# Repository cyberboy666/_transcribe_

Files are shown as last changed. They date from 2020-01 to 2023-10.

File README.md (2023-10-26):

# \_transcribe\_

### midi to rs232 bridge - for performance control of old video mixers and switchers



- this circuit is distributed by __UNDERSCORES__ - _an open video hardware label_ : it is available to purchase - as a pcb, kit or assembled unit - at [underscores.shop](https://underscores.shop/_transcribe_/)
- the schematic for the circuit can be found [here](/hardware/schematic.pdf)
- the pcb gerber files for the lastest version can be found [here](/hardware/gerber_latest.zip)
- interactive BOM is [here](https://htmlpreview.github.io/?https://github.com/cyberboy666/_transcribe_/blob/main/hardware/bom/ibom.html)
- consider [donating](https://opencollective.com/underscores) to the underscores project to help us continue creating for the commons
## description

people in the video-art community are performing with old hardware video-mixers such as the Pansonic_WJ_AVE55 and Pansonic_WJ_MX30/50. some of these mixers have a RS232 serial port for interfacing with them digitally. this is especially useful for live performance where sequencing can assist physical actions. there are some cool examples of software specifically written to interface with these mixers (such as [Freds excel app](https://a2m2.ch/fred/wj-ave55.htm) and  [Klifs MaxPatch](https://vimeo.com/161662975) ) , but there many more programs and devices that are made to interface digitally using MIDI.

the aim of this project is to create a small utility module that can __\_transcribe\___ _MIDI_, a protocol used commonly in live&performance instruments to the specific _RS-232 video-device specification_ , to better equip these retired workstations for their new life of glamour on stage

- input USB-midi from a USB-HOST such as a computer or rpi
- input serial-midi from older midi devices (din5)
- input USB-midi for a USB-DEVICE such as a korg nanokontroller or otherwise
- output RS232-serial commands over 3.5mm jack or dsub9 socket to control panasonic video-mixers and other devices
- all these interfaces are bi-directional and so can be modified with firmware to do other useful things (eg like a USB-DEVICE -> SERIAL midi converter)

## demo video

(https://videos.scanlines.xyz/w/iJpDAtjqwNczxP9pRJbMGW)

# documentation

this project is fully _open-source hardware_ - all the files required to build it are included in this repo for free. if you have the time and/or skill you can contribute back by collaborating on / testing new designs, improving these docs, making demo videos/other creative content etc. you can also support the project financially by [donating directing](https://opencollective.com/underscores), or purchasing through the [web shop](https://underscores.shop).

depending on whether you are going fully diy or buying an assembled and tested unit, some of the following guides will be relavent to you. the flow would be:

## ordering parts

<details><summary><b>parts sourcing guide (w/ notes on pcb fabracation )</b> - start here if you are building fully from scatch or have purchased a pcb</summary>

i try to source all the parts i can from either:
- [tayda](https://www.taydaelectronics.com/) ; cheaper for common parts like resistors etc, also good for mechanical parts like switches and buttons
- [mouser](https://www.mouser.de/) ; has lots more options, speciality video ic's, can sometimes cost more (free shipping on orders over 50euros)
- other ; ocationally there will be parts which will need to be sourced elsewhere - usaully either aliexpress, ebay or amazon etc...

take a look at the [full_bom](/hardware/bom/full_bom.csv) for this project to see where i am sourcing each part from
  
## omitting parts
  
if you know exactly how you will use your _transcribe_ some parts of this circuit build can be omitted. the pcb is divided into sections that are marked on silk-screen:

- __A - micro-conntroller - centre__ : this is the brain of the circuit and is required to make it do anything. its also where USB_MIDI is received from(/sent to) usb-hosts (eg computer or raspberry pi)
- __B - rs232 serial - output(/input)__ : for sending(/receiving) serial at rs232 levels - only omit if you are not using this board for its default / intended purpose
- __C - serial midi - input(/output)__ : for receiving(/sending) midi messages over serial (usually on older hardware over din5 or 3.5mm jack) - can omit if you are only using (newer) hardware with USB-MIDI
- __D USB-midi HOST__: adds circuitry so that micro-controller can act as USB-HOST. for receiving midi messages from(/sending to) usb-devices (eg korg nanokontrol2) - can omit this if not interested in controlling from usb-devices

## import into tayda

- go to the [tayda quick order](https://www.taydaelectronics.com/quick-order/) and in bottom corner choose _add from file_
- select the file [tayda_bom.csv](./hardware/bom/tayda_bom.csv) in the BOM folder (you will have to download it first or clone this repo)
- after importing select _add to cart_
- __NOTE:__ the minimum value for resistors is 10, so you may need to modify these values to add to cart (or if they are already modified here you will need to see the  full_bom for actual part QTY) 

- OPTIONAL: it is a good idea to add some dip-ic sockets and 2.54pin headers/sockets to your tayda order if you dont have them around already
  
## import into mouser

- go to [mouser bom tool](https://nz.mouser.com/Bom/) and click _upload spreadsheet_
- select the file [mouser_bom.csv](./hardware/bom/mouser_bom.csv) in this folder (you will have to download it first or clone this repo), then _upload my spreadsheet_ and _next_
- ensure that __Mouser Part Number__ is selected in the dropdown above the first row, then _next_, _process_
- if everything looks correct can now put _add to basket_

# ordering pcbs

you can support this project by buying individual pcbs from the [shop](https://underscores.shop). if you would rather have pcbs fabricated from gerbers directly the file you need is [here](/hardware/gerber_latest.zip) 

- i get my pcbs fabricated from [jlcpcb](https://cart.jlcpcb.com/quote) - 5 is the minumum order per design
- upload the zip file with the `add gerber file` button
- the default settings are mostly fine - set the __PCB Qty__ and __PCB Color__ settings (you can check that the file looks correct with pcb veiwer)
- it may be best to combine orders with other pcbs you want to have fab'd since the shipping can cost more than the items - also orginising group buys is a good way to distribute the extra pcbs /costs 
  
i often use jlcpcb because they are reliable, cheap and give you an option of colours. remember though that the cheapest Chinese fab houses are not always the most ethical or environmently friendly - if you can afford it consider supporting local companies. 

</details>

<details><summary>a note on midi over 3.5mm trs jacks</summary>

in general newer devices send midi over usb, and older ones send serial-midi over _din5 jacks_. however some newer devices opt to send serial-midi over __3.5mm trs jacks__ (to save space on more compact designs)

_transcribe_ has (overlapping) footprints for either serial-midi over _din5_ or over __3.5mm trs__

unfortunately at the time that designers started using __3.5mm trs jacks__ for midi there was no offical standard for which pins map to midis _source_ (`midi_plus`) and _sink_ (`midi_data`) pins and different designers have mapped this differently on their instruments.

now there is an offical standard - TYPE A - which is what _transcribe_ uses: 

- t -> _sink_ (data)
- r -> _source_ (plus)
- s -> x

[minimidi.world](https://minimidi.world/) is a great resource that explains the different standards and allows you to look up the type of _serial midi over 3.5mm trs_ that your devices have - i recommend taking a look at this if you are planning on using 3.5mm trs with your _transcribe_

</details>

## assembly guide

<details><summary><b>assembly guide</b> - start here if you have purchased a diy kit</summary>

## interactive BOM for build guiding

follow this link to view the [interactive BOM](https://htmlpreview.github.io/?https://github.com/cyberboy666/_transcribe_/blob/main/hardware/bom/ibom.html)

## general solder advices

- remember to heat pad first (2-3seconds), then add solder, then continue to heat (1-2seconds)

- Checkout the web-comic [soldering is easy](https://mightyohm.com/files/soldercomic/FullSolderComic_EN.pdf) for more soldering advice

## general order of assembly

- in general while assembling i start placing resistors and capacitors first. placing 5 - 10 components at a time and then flipping the board to solder them and trim the legs etc.
- next i would do diodes, transistors and ic's - taking care that these are placed in the right direction (using a ic socket can be useful)
- finally i place the interface parts - rca jacks, power jack, pots and switches - make sure these have lots of solder on for structural stablity

## interface choice / double footprint
  
_serial-midi_ is most commonly sent over __din5__ (older hardware) J5 & J7 or __trs 3.5mm jack__ (newer hardware) J4 & J6 - footprints for both are overlayed on the pcb so you can choose which one you would like to have
  
## Usb-host shield

__IMPORTANT: A trace needs to be cut on the usb-host-shield to allow it to be powered by 5v__ – _see the diagram below_ – this is best done with a craft knife – take care not to cut any other traces accidentally.
  


  
all pins on the outer vertical lines need to be soldered to the board. In addition to this the single topmost inner pin (labeled 5v in diagram) needs to be soldered to pcb also
  
## specific assembly advice

Start by soldering the smallest parts first: resistors, diodes, capacitors and regulators - take note of the direction on the diodes - black bar on component matching black bar on footprint

Next lets do the ic’s/sockets - make sure the direction is correct! place in and fold two corner pins to hold in place, then solder all pins. you can place the ic in now too

Now lets do the micro-controller and usb-host-shield - if you want to be able to remove them from the board you will need to solder header sockets to the board first – otherwise can directly solder the header pins

for the usb-host-shield right_row I would do a 1x2 header horizontally at the top to catch that 5v pin and then 1x11 row vertically for the rest – the left_row can just be a single 1x12 vertical header

Finally place the interface parts (eg jacks and sockets) be generous with the solder here -> this is to strengthen the mechanical connections as well as making electrical ones

Leave j8 header unpopulated – this just exposes the bootloader pins so firmware can be reset in the rare case that the pro-micro gets bricked – also leave j1 header unpopulated unless you want to power from a euro-power-header
  
</details>

## firmware guide

<details><summary><b>firmware guide</b> - for editing the code & flashing it to your micro-controller</summary>
  
## flashing firmware onto the micro-controller
  
if you have got a kit from the shop the default firmware will be pre-configured - still you probably will want to follow this so you can edit the code and update the mappings.
  
### install guide
  
all _underscores_ projects with micro-controllers use [platformio](https://platformio.org/) with [visual studio code](https://code.visualstudio.com/) to edit, flash and monitor the code.
  
- first download (and unzip) the code in this repo - easiest is [as a zip](https://github.com/cyberboy666/_transcribe_/archive/refs/heads/main.zip) or you can clone using git if you are comfortable with this
- next download, install and open [visual studio code](https://code.visualstudio.com/#alt-downloads)
- now open the extension tab within vscode on left vertical menu (or press ctrl-shift-x) and search for `platformio` to install this extension
  


- connect the micro-controller to computer via usb, open the _transcribe_ software folder (ctrl-k ctrl-o) in vscode and find the _platformio_ commands (either in left vertical menu under _platformio_ or little tick/arrow symbols along bottom blue bar) - `PlatformIO: Upload` should flash the default code to your micro-controller
  


### mapping edit guide
  
this guide is just an overview to get you started. the two files that you might want to look at are: 
- [software/src/commands.h](software/src/commands.h) - where the specific serial protocol commands are defined
- [software/src/main.cpp](software/src/main.cpp) - all the code that handles receiving midi and writing serial is - including the _mapping function_
  
open the `src/main.cpp` file in vscode and fold all functions by pressing `ctrl-k, ctrl-0` - this makes reading it a bit easier:



open and take a look at the `setAVE55nanokontrolMap` method - we will first look at these lines:
  
```cpp
    else if(midiParam1 == 64){setCmd(A55_A_BUS_SOURCE_1);}
    else if(midiParam1 == 65){setCmd(A55_A_BUS_SOURCE_2);}
```
  
the first line is saying: __if the incoming midi message has `midiParam1` set to 64, then send the `A55_A_BUS_SOURCE_1` command over rs232 serial__ - since we can see from above that this line is within the conditional: `if(midiCommand == MIDICOMMAND::CC)` , then we know that `midiParam1` is refering to the cc channel. we can also see in the __commands.h__ file  that `A55_A_BUS_SOURCE_1` is set to the command from that panasonic ave55 specification that switches the a-bus source to input 1:
```cpp
  #define A55_A_BUS_SOURCE_1 "VCP:200"
```

this line is mapping a midi message on cc channel 64 to the rs232 message for ave55 that switches the input source. this is the simplest kind of mapping - a discrete BUTTON press. however there are also mappings to functions that take parameter values also. for example the `A55_A_B_MIX_LEVEL` command that wipes between the a-bus to b-bus on the mixer:
  
 ```cpp
 if(midiParam1 == 0){setCmd(A55_A_B_MIX_LEVEL, midiParam2);}
 else if(midiParam1 == 1){setCmd(A55_THRESHOLD_LUM_KEY, midiParam2);}
 else if(midiParam1 == 2){setCmd(A55_CENTER_WIPE_X, midiParam2);}
 else if(midiParam1 == 3){setCmd(A55_CENTER_WIPE_Y, midiParam2);}
```

we can see that on these mappings also the __midiParam2__ value is passed into the _setCmd_ function - this is the _cc value_ of the channel - on my controller - the position of the slider that is sending on cc channel 0. the rs232 command for this function also takes a varible input to set position of the mix:
```cpp
#define A55_A_B_MIX_LEVEL "VMM:179~0"
```
where the `~0` is a placeholder that is replaced with the hex-converted value of `midiParam2`. there are other ways to map midi notes to rs232 commands. there are more 'advanced' mapping functions in the code for this - for example:
```cpp
else if(midiParam1 == 35){setCmdParamRandom(A55_A_B_MIX_LEVEL);}
```
takes a button press and converts it to a random mix level. another useful mapping is taking continuous inputn (eg slider on midi controller)  and convert this to a STEP of different discrete commands - for example:
```cpp
else if(midiParam1 == 17){setCmdStepAVE55(A55_A_BUS_MOSAIC_OFF, midiParam2, 76, 6);}
else if(midiParam1 == 18){setCmdStepAVE55(A55_A_BUS_PAINT_OFF, midiParam2, 82, 6);}
```
these mappings STEP between sending 6 different rs232 commands on a single slider - so you can set all the mosaic/paint effect levels in one turn. another useful 'advanced' mapping function is the SWITCH:
  
```cpp
else if(midiParam1 == 50){setCmdSwitch(MX50_A_BUS_EFFECT_ON, MX50_A_BUS_EFFECT_OFF, 3);}
```

this will SWITCH between sending the _on_ and _off_ commands when the same midi command is send (the third parameter input `3` is a unique index reference to store the on/off state in memory between messages)
  
these are just some examples of the ways that code can be used to perform these mappings. if you are interested can see more in the code directly or write your own mapping functions!

</details>
  
## operating guide
  
<details><summary><b>operating guide</b> - start here if you have purchased an assembled unit</summary>



</details>

### more info

<details><summary><b>how the circuit works</b></summary>
  
[coming soon]
                                                                                                                             
</details>

<details><summary><b>contributing guide</b></summary>
  
if you would like to contribute back to these projects in some way but dont know how the best thing (for now) would be to reach out to me directly ( tim@cyberboy666.com or @cyberboy666 on scanlines forum) - i will be happy to help
  
</details>

## credits & more info

This circuit is distributed through UNDERSCORES – open video hardware label – visit [underscores.shop](https://underscores.shop) for more info

The pcb was designed using KICAD

Everything from gerbers, cad files, panels and documentation is freely available online and distributed under CC-BY-SA / open-source licenses – help us contribute to the commons !

Ask any questions or start discussions related to this project on the [scanlines.xyz](https://scanlines.xyz) forum – an online community space dedicated to diy av / electronic media art

You can contact me directly at tim (at) cyberboy666 (dot) com 
Please get in touch if you are interested in hosting a workshop !



Thanks to Gilbert Sinnott for helping with initial experiments. to Bastien Lavaud for circuit advice, always. To Ben Caldwell for project advice. To everyone who has or will contribute ♥♥♥

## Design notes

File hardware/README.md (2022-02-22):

# _transcribe_ hardware

this is the hardware section of _transcribe_ - a project created to control panasonic video_mixers with midi.

# BOM

Reference | Qty | Value | source | source-id | section
--- | --- | --- | --- | --- | ---
? | 1|  _transcribe_ pcb | me? or a fab-house | ...  | all
C1 | 1 | 100uf | tayda | [A-1063](https://www.taydaelectronics.com/catalogsearch/result/?q=A-1063) | A 
C2, C3, C4, C5 | 4 | 0.1uf | tayda | [A-4008](https://www.taydaelectronics.com/catalogsearch/result/?q=A-4008) | B
D1, D2 | 2 | 1N4148 | tayda | [A-157](https://www.taydaelectronics.com/catalogsearch/result/?q=A-157) | C
J1 | 1 | europower header (optional) | tayda | [A-2956](https://www.taydaelectronics.com/catalogsearch/result/?q=A-2956) | -
J2, J4, J6 | 3 | AudioJackTSR | tayda | [A-853](https://www.taydaelectronics.com/catalogsearch/result/?q=A-853) | B , C
J3 | 1 | DSUB9 | tayda | [A-300](https://www.taydaelectronics.com/catalogsearch/result/?q=A-300) or [A-301](https://www.taydaelectronics.com/catalogsearch/result/?q=A-301) | B , C
J5, J7 | 2 | DIN-5 | tayda | [A-1010](https://www.taydaelectronics.com/catalogsearch/result/?q=A-1010) | B , C
R1, R2, R3 | 3 |  220 | tayda | [A-3755](https://www.taydaelectronics.com/catalogsearch/result/?q=A-3755)  | C
R4 | 1 | 10k | tayda | [A-2275](https://www.taydaelectronics.com/catalogsearch/result/?q=A-2275)  | C
U1 | 1 | ProMicro5v | [ali](https://www.aliexpress.com/item/1348800135.html) [amazon](https://www.amazon.com/OSOYOO-ATmega32U4-arduino-Leonardo-ATmega328/dp/B012FOV17O/), [sparkfun](https://www.sparkfun.com/products/12640) | - | A
U2 | 1 | MAX232n | tayda | [A-034](https://www.taydaelectronics.com/catalogsearch/result/?q=A-034) | B
U3 | 1 | 6N137 | tayda | [A-871](https://www.taydaelectronics.com/catalogsearch/result/?q=A-871) | C
U4 | 1 | 4069 |  tayda | [A-882](https://www.taydaelectronics.com/catalogsearch/result/?q=A-882) | C
U5 | 1 | usbHostMini | [ali](https://www.aliexpress.com/item/32842815739.html) [amazon](https://www.amazon.com/HiLetgo-Development-Compatible-Interface-Arduino/dp/B01EWW9R1E/) | - | D
U6 | 1 | 78L33 | tayda | [A-492](https://www.taydaelectronics.com/catalogsearch/result/?q=A-492) | D

<details><summary>CORRECTION FOR CIRCUIT V0.2 AND LOWER</summary>

if you have circuit revision 0.2 or lower then there is a mistake on the footprint of the dsub9 connector sorry (serial from the 3.5mm jack to ave55 works fine) follow the following steps to get serial from the dsub9 header on these boards:

- solder the DSUB9_HEADER onto the bottom of the board
- from here pins 2 and 3 need to be swapped
- cut both traces going to dsub (the traces going between and around c2)
- wire the other ends pin13 and pin14 of u2 to the pins on dsub. u2_pin13 to dusb_pion3 and u2_pin14 to dsub_pin2 
- finally due to another error on the board IF you have placed the 3.5mm jack at J2 THEN you must have a stereo cable plugged into this to use the DSUB9 output (otherwise signal is grounded)




</details>

## potential additional parts to add : 

## assemble guide :

- i soldered the resistors, capicitors, diodes and regulator first, then the ics(/sockets) and pin headers, then the jacks
- i used pin sockets to attach the pro-micro and usb host to board in detatchable way (helpful for debugging) but this is up to you

blah blah blah

IF USING USB_HOST_MIDI YOU __MUST CUT A TRACE__ ON THE BOARD ! heres how - ...

the trace you need to cut is going into the resistor labelled 2.2k in the top corner near the usb socket




# explaining the sections of _transcribe_

 _transcribe_ is based around an arduino micro controller. included in this circuit are a number of different ways to input midi and output serial. you can choose which sections to populate based on your personal requirements.

## A - micro-conntroller - centre

this is the brain of the circuit and is __required__ to make it do anything. i am using a sparkfun pro-micro 5v, which uses micro-usb as power. (it is likely this circuit will also work with an arduino nano - which will require a seperate version of the pcb - but watch this space)

## B - rs232 serial - output(/input)

panasonic video mixers (and other older devices) use a different serial standard (RS232) to micro-controllers (ttl). in this section serial commands from the uC are level-shifted to be recongised by these devices. _only obmit this section if you are not interested in controlling old (rs232) gear_. the data is exposed on a 3.5mm TRS (stereo) jack; tip - input, ring - output, sleave - ground.

NOTE - although not used by the default firmware, the hardware also allows rs232 serial input, so this porject could be modified to also control something _from_ old gear

## C - serial midi - input(/output)

the uC (in A) can act as a USB midi _device_. this means it can be controlled by a USB midi _host_ (such as a computer running abeton, or a raspberry pi). this section includes the additional circuity to also control it with serial-midi (often seen on older instruments with din5 type plugs)

NOTE - although din5 plugs are often used for connecting old gear with serial midi, these sockets can be bulky and sometimes difficult to find. for this reason newer gear supporting serial-midi often use TRS jacks - leaving the standard-conversion to cables. i would use 3.5mm TRS (stereo) also for midi in and out, with tip - midi data (din-pin4), ring - midi plus (din-pin5), sleave - unconnected (or include a switch to swap tip/ring...)

NOTE - although not used by the default firmware, the hardware also allows serial-midi output, so this project could be modified to also output serial midi

_obmit this section if you are not interested in interfacing with 'old style' serial midi_

## D USB-midi HOST

the uC (in A) can act as a USB midi _device_. this means it can be controlled by a USB midi _host_ (such as a computer running abeton, or a raspberry pi). this section includes additional circuitry to allow the uC to also act as a USB midi __HOST__. this means it can be controlled by a USB midi _device_ such as a korg nanokontroller (or many other external usb-midi controllers/ gear). _obmit this section if you are not interested in controlling from a usb-midi device_

# section summary

## video-mixer controlling options:

- control rs232-mixer with usb-midi from host : A + B
- control rs232-mixer with serial-midi : A + B + C
- control rs232-mixer with usb-midi from device : A + B + D

## some bonus converting options:

- convert usb-midi controller to serial midi : A + C + D
- convert rs232 commands to serial-midi : A + B + C
- use a ps3 controller to send serial-midi : A + C + D

## build notes for v0_5

- decide on what sections you want to build (ie need to have A, probably you want to send out serial so also add B. do you want usb-midi ? then add D, do you want serial midi in/out ? then add C etc)
- also decide what kind of serial midi ins/out jack you want - old style din5 or new 3.5mm jack ?
- i started by placing and soldering the caps and resistors, then diodes and regulator (check orientation!)
- i like to solder in pin sockets for the pro-micro and usb-header part so they can be removed if i upgrage the circuit design - this is up to you -> will need to solder in the pins onto the pro-micro and usb-host shield if not already done. note the extra pin needed on host and the trace that needs to be cut!
- if using pin sockets do this next - when cutting the sockets to fit aim your wire cutters exactly on the adjacent socket (one more) than you need - this is to ensure the pin part doesnt fall out of the socket you need when cutting. you may need to bend u6 down abit to fit socket in
- now place the j9 pins (and two jumpers setting the serial pins on din9) and the ic/ic_sockets
- finally can solder on the interface parts - midi ins and outs, din9 and 3.5mm jacks
- note dont need to solder anything on for u5 pins - this is just exposing pins on the pro-micro so it can be reflashed incase of critical error flashing - dont need to place the euroheader either - this is just incase you want to give 5v from an existing europower rail (take care of orientation of the header if doing this)

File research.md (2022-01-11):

whenever i start a project i like to keep a list of ideas, thoughts, srceen-caps and todo lists in one place

# _transcribe_
for midi control of panasonic video mixers

## idea / overview

promicro setup : https://learn.sparkfun.com/tutorials/pro-micro--fio-v3-hookup-guide/all

.... some links here, explaining ...

- take midi in (see different ways below)
- send serial out (for ave55)
- convert to r232 with max232 chip
- connect to 3.5 trs jack

https://arduinodiy.wordpress.com/2012/03/19/serial-connection-for-your-arduino-atmega

wiring max232n : 







## want to support for : 

### usb midi device

usb midi from a host ie computer, pi etc, this should be the easiest to implement

### serial midi

from din midi devices - for this would have to have 2 serial ports, one listening to midi in, and one writing to ave55 out, i thin k the best thing to try is midi on the hardware serial and ave55 on [AltSoftSerial](https://www.pjrc.com/teensy/td_libs_AltSoftSerial.html) , altSoftSerial on pro micro is missing the input pin , but it seems this can be modded in without too much trouble : https://forum.arduino.cc/index.php?topic=339587.0

### usb midi host

from things like nano control - needs a host shield - maybe like [this](https://www.aliexpress.com/item/32942427334.html) one : 

reading midi from host and outputting as serial : https://github.com/felis/USB_Host_Shield_2.0/blob/master/examples/USBH_MIDI/USB_MIDI_converter/USB_MIDI_converter.ino
question about mini-host and pro-micro : https://github.com/felis/USB_Host_Shield_2.0/issues/392
an old thread talking about hooking these up together : https://forum.sparkfun.com/viewtopic.php?t=34873
another thread about hooking these up: https://forum.pjrc.com/threads/43357-Teensy-with-mini-USB-host-shield-(chineese)

### further research into using the usb-host:

- it seems that the vbus (5v) needs to be cut from the vcc (3.3v) , here is best example : https://www.arduino.cn/thread-81435-1-1.html
- i need a 3.3v power source for the usb-host , prob best bet is a L78L33 (18c, up to 100ma) or LM1117T (99c up to 800ma)
- for the wiring , in theroy a level-shifter should be used between 5v arduino and 3.3v ic (74HC125) , but people have reported success with a arduio nano , which is also 5v so im thinking maybe this will also just work ?? but other places suggest it wont ,, im not sure - should try this circuit with a 3.3board too ?
- also a 100uF cap in line with the power is reccomended here : https://www.pjrc.com/teensy/td_libs_USBHostShield.html

- for the wiring , it should look something like this :

host | pro-micro | name
--- | --- | ---
5 | ? | ss
6 | 16 | mosi
7 | 14 | miso
8 | 15 | sck
2 | ? | int
1 | vcc | 5v
9 | regulator | 3.3v
3 | gnd | gnd
4 | rst | rst

- also suggested to wire rst to power ... 

HOST


some more useful info about the host :
- https://www.hackster.io/139994/plug-any-usb-device-on-an-esp8266-e0ca8a
- https://web.archive.org/web/20190120133645/https://www.circuitsathome.com/usb-host-shield-hardware-manual/

## other panansonic (or other) mixers

- panasonic ave55 is rs232 on a stereo 3.5mm jack

- mx50 has a rs232 / rs422 switch , the interface is a 9pin dsub (with a bunch of confusing swtiches / settings)
- mx30 has 9pin dbus with rs232
- mx20 has serial on a mini-din , it says rs422 - hard to tell if it will work or how to make it ...
mx70 has 9pin dsub with rs232 also
- others ??

## some ideas of ideal structure

- ~~a list of mappings between serial commands and midi notes/ccs~~
- ~~continuous controls -> cc values (ie mix position...)~~
- ~~buttons -> notes or cc (sources, )~~
- ~~switches (toggles) -> single note/cc (ie pressing once for on, again for off ?)~~
- ~~range of values (steps) -> cc values (ie paint0, paint1, paint2, paint3)~~

## some things to check / try / do

- try with the level-shifter circuit - i tried but it didnt work - maybe my circuit was wrong tho
- ~~try with smaller caps~~ this works horray
- ~~try with altSoftSerial~~ - seems to work
- ~~try with serial midi input (how?) maybe i will need to work with 2 arduinos , one for sending midi another for receiving~~
- ~~try with usb midi host sheild~~ 
- implement other types of commands (random / osolatoer etc .. )
- create a pcb design

## looking at other  mixers

the other panasonic mixers i know about have a different way of inputing serial... dont even know if this is compatable or works in the same way..

### mx 50 wiring



### mx 30 wiring



crazy that even these two arnt wired the same way ! but maybe only the (tx/rx/gnd matter anyway...)

### mx 20 wiring



dif plug, (mini din) and i think dif wiring too - looks like , oof it makes no sense ! (no mention of buad rate or stop byte or anything really on this one) , maybe not possible to support this one ...

### kramer vs-402 serial spec



## from wikipedia :



# burning the bootloader

it is known that the sparkfun promicro can from time to time get into a state where the port is not recognised, or difficult to upload new code to it - there is a complicated method of grounding the reset pin some times and then quickly uploading new code - i have tried this and though it works sometimes , it also is very frustrating and can just become a problem again the next time you try to upload some code. 

instead i am going to explore the method of reburning the bootloader on the pro-micro, hopefully this will fix the problem more permanently. and after the intial time taken to learn how to do this, it will also save time working on this project, and any others with pro-micros. as a side note - this could also be useful for burning/uploading code to the dip-atmega ics you can get for $2 from tayda...

this [sparkfun article](https://learn.sparkfun.com/tutorials/installing-an-arduino-bootloader) is a good introduction to the idea.

i dont have an uno, but do have an arduino nano here - so will try using this as the ISP. sounds like even another pro-micro will work as ISP according to [this forum](https://forum.arduino.cc/index.php?topic=199524.0) post, but they have caused enough trouble for now !

first i uploaded the ArduinoISP sketch to the nano (using the old bootloader version) , 
then hooked them together with some wires:

the connections were: with spi->spi (miso, mosi, clk), and ss -> rst, plus power/gnd ; exactly the same as in this guide https://www.instructables.com/id/Burn-Bootloader-Arduino-Nano-As-ISP-to-Pro-Micro/ ; also i put a 10uf cap reset -> +| |- ->gnd on the nano

then in the arduino ide i chose the pro-micro board, changed the programmer to `arduino as ISP` then pressed `BurnBootloader`. this worked no problem ! very painless. at first i followed the intructable above and loaded with the  `arduino Micro` board selected, but this did weird things with the leds , and although it still worked, after trying with my other 'not working' pro-micro , this newly updated one also started having problems.. i then went back and reburnt the bootloader , now with `sparkfun pro-micro` board selected - this fixed the weird led thing.

even with the pro-micro burnt, if i try upload code with the problem board, then swich the cables to a fresh and working one (even with a reset of vscode between) it will pass on the problem to this fresh board. luckly reburning the bootloader is very quick if you have the nano set up and ready to go. i will keep this ISP nano handy on the breadboard while developing on the pro-micro in case this problem starts again.

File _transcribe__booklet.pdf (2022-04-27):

# _transcribe_

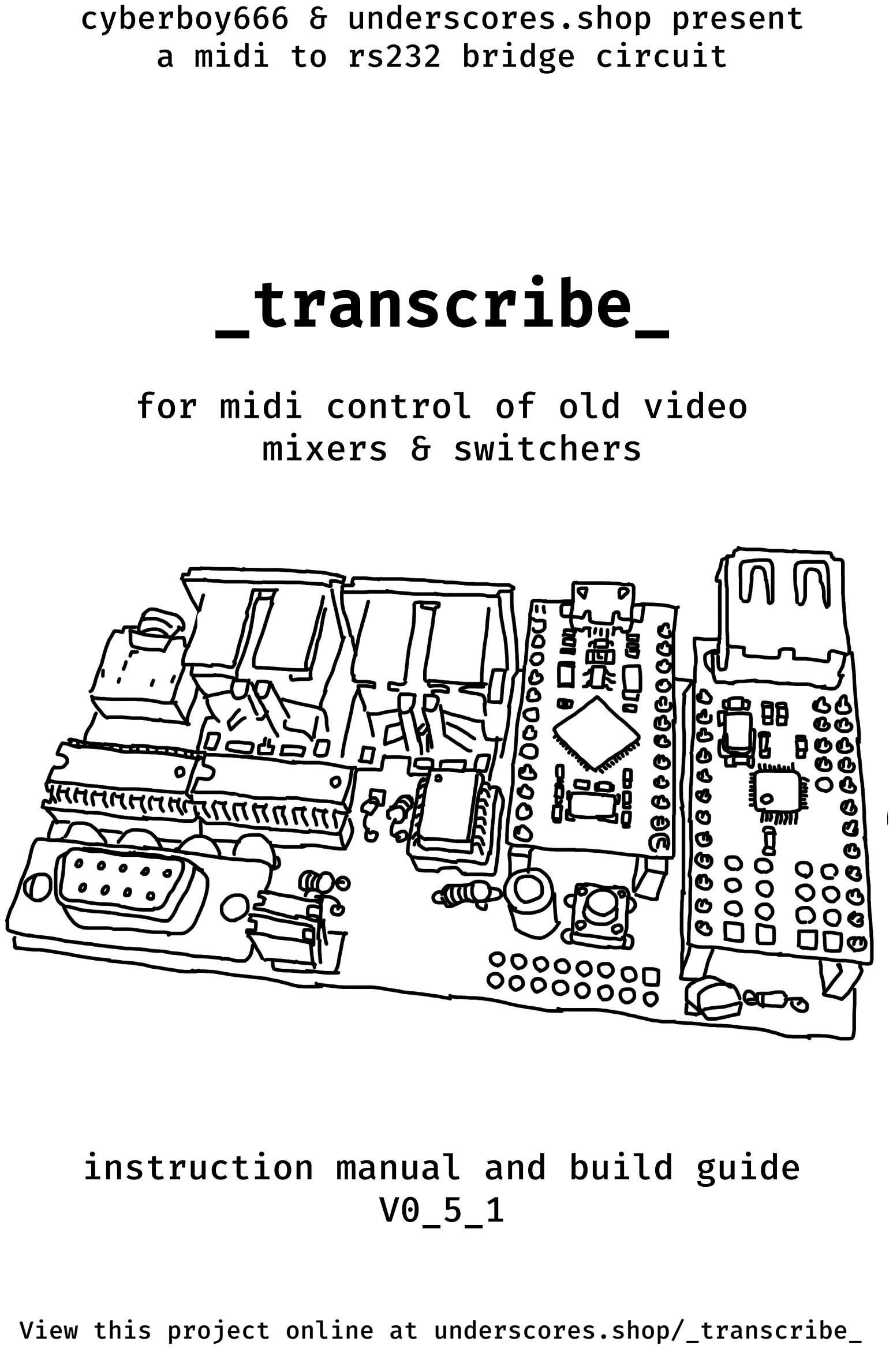
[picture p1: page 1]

cyberboy666 & underscores.shop present a midi to rs232 bridge circuit

### for midi control of old video mixers & switchers

### instruction manual and build guide

## V0_5_1

View this project online at underscores.shop/_transcribe_

\

# INTRODUCTION

the _transcribe_ circuit is a midi to rs232 serial utility module aiming to give better integrated performance capability to older/obsolete video gear.

some old video mixers and switchers have their own serial command specifications for externally controlling them. the arduino micro-controller in _transcribe_ runs open source firmware that maps incoming generic midi messages to these specific serial commands.

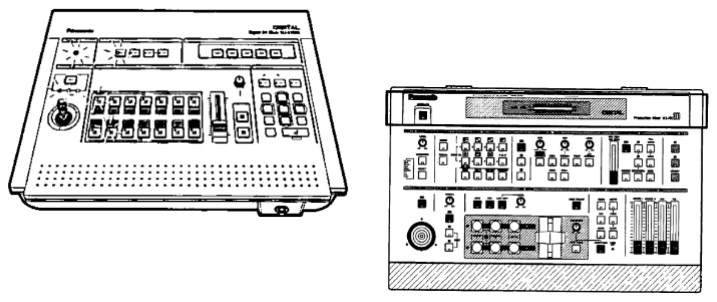
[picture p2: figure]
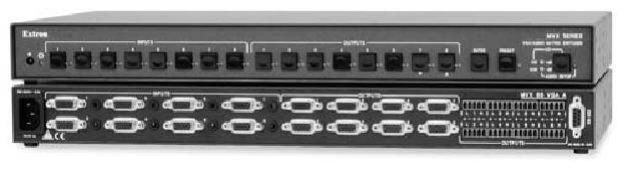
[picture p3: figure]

- So far _transcribe_ is tested and supported with:
- Panasonic ave55
- Panasonic mx30/50 (partial)
- Extron video switchers
- Kramer video switchers

More devices will be added as people start experimenting with the gear they have around – let me know if you are interested in helping add support for something!

# FIRMWARE MAPPING

although no coding background is required for this project, you will need to be comfortable following install instructions and hacking at a few lines of arduino code to customize and set up your own midi to rs232 mapping

There are guides to both installing the required software and in-depth explanations to how the code that does the mapping works on the projects github page: github.com/cyberboy666/_transcribe_

An example of a default mapping for the panasonic ave55 can be seen below

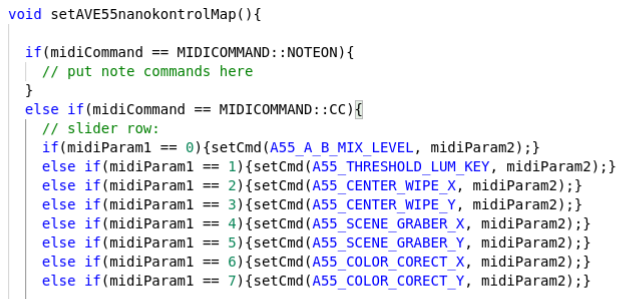
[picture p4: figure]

Don’t worry if all this doesn’t make sense initially – most of the heavy lifting being done under the hood, you just need to say on which midi messages should trigger which serial commands.

However if you do know some c++ theres room in the code to add some esoteric and fun mapping functions such as setting random wipe positions and types on every note etc..

# OPERATING INSTRUCTIONS

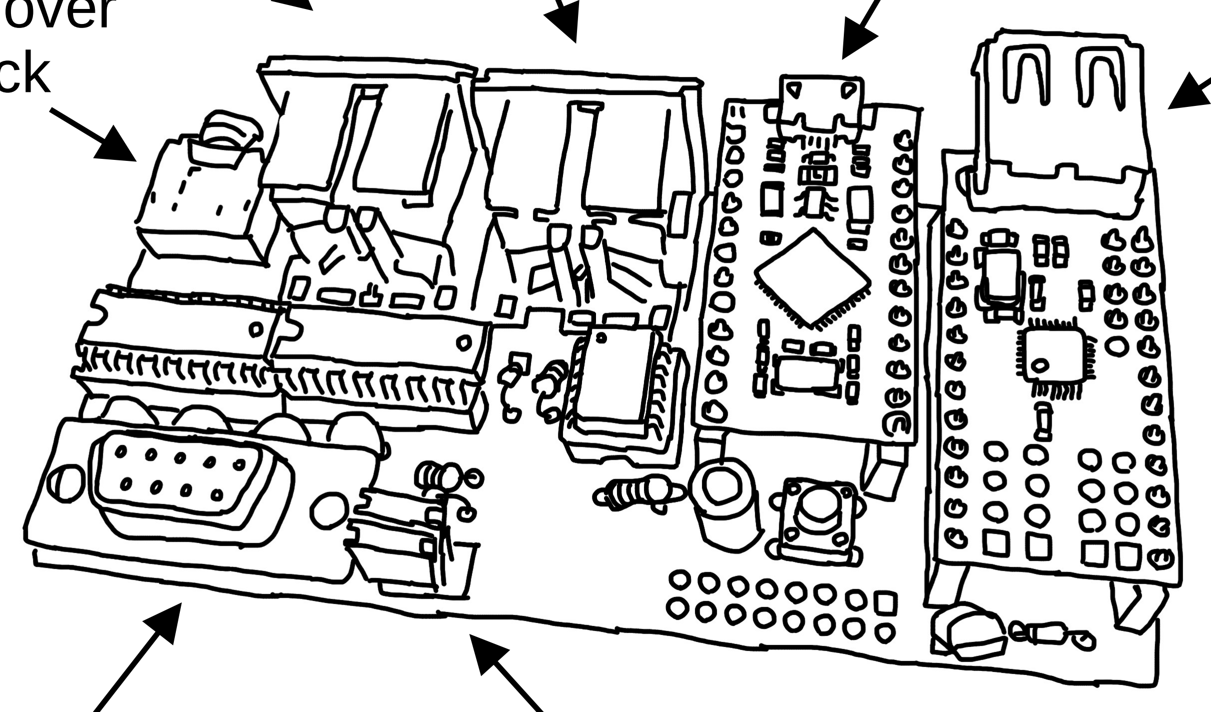
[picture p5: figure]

There are a few different options for inputting midi into _transcribe_ and outputting serial, depending what you are connecting to it:

- input USB-midi from a USB-HOST such as a computer or rpi
- input serial-midi from older midi devices (din5)
- input USB-midi from a USB-DEVICE such as a korg nanokontroller2 or otherwise
- output RS232-serial commands over 3.5mm jack or dsub9 socket to control panasonic video-mixers and other devices
- all these interfaces are bi-directional and so can be modified with firmware to do other useful things (eg like a USB-DEVICE midi -> SERIAL midi converter)

rs232 serial over
3.5mm jack

midi from USB-DEVICES

serial midi in

rs232 serial
over din9 | jumper select
| din9 serial pin

serial midi out
5v power / midi from
USB-HOSTS

# OPERATING INSTRUCTIONS CONT

power

If you are not using micro-usb input on the uC to send midi you can power the circuit here by connecting usb cable to a wall adapter. Alternatively power can be supplied by the 5v line on a euro-power-header

midi input

The small tact button beneath the uC needs to be pressed to connect the usb-midi-device (eg nanokontroller) after it has been plugged in to the USB-A jack on the host-shield.

Serial midi and midi from usb-hosts will connect automatically

rs-232 output

RS-232 serial is most commonly sent over dsub9 cables with transmit messages on pin3 and receive messages on pin2 – however some devices such as Kramer switchers expect this reversed, with transmit messages on pin2 – for this reason _transcribe_ has pin_jumpers (j9, j10) the left position is default.

_transcribe_ also can the send rs-232 over 3.5mm trs stereo cables – where tip is transmit, ring is receive and sleeve is ground.

# BUILD INSTRUCTIONS

It is highly recommended to use the interactive BOM to help with placement on this build – type kutt.it/zLP9yE into a browser or find the links from the github page

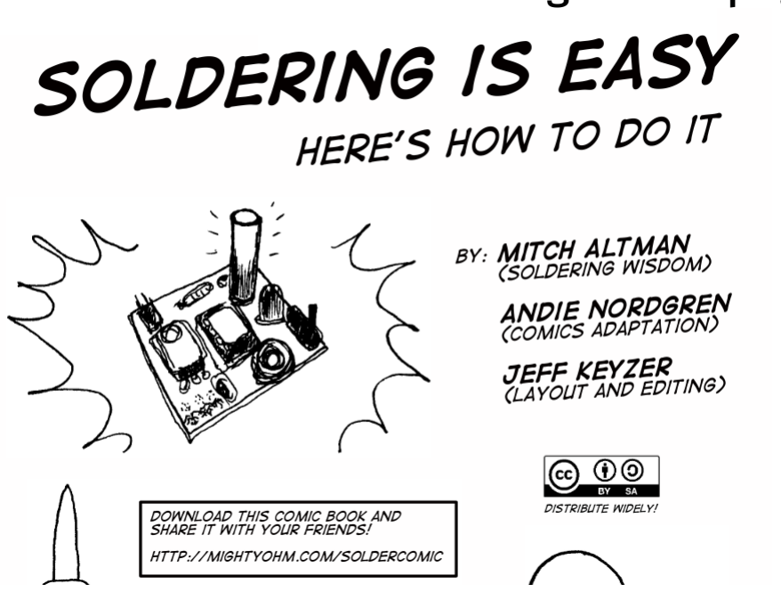
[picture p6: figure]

interface choice / double footprint

serial-midi is most commonly sent over din5 (older hardware) J5 & J7 or trs 3.5mm jack (newer hardware) J4 & J6 - footprints for both are overlaid on the pcb so you can choose which one you would like to have

Usb-host shield

A trace needs to be cut on the usb-host-shield to allow it to be powered by 5v – see the diagram below – this is best done with a craft knife – take care not to cut any other traces accidentally.

note on soldering: remember to heat pad first (2-
3seconds), then add solder, then continue to heat (1-
2seconds)

Checkout the web-comic
soldering is easy for more soldering advice

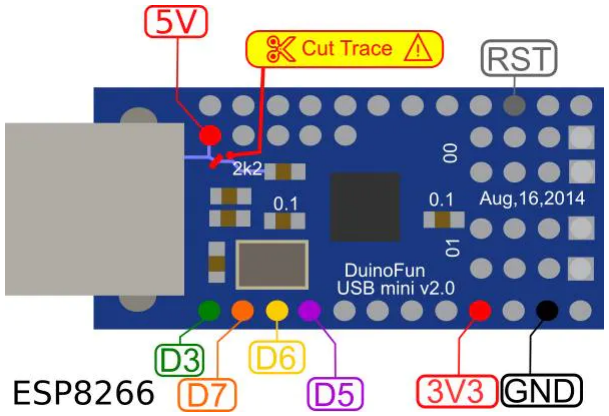
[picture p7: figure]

All pins on the outer
vertical lines need to
be soldered to the
board.

In addition to this the
single topmost inner
pin (labeled 5v in
diagram) needs to be
soldered to pcb also

BUILD INSTRUCTIONS CONT.

- Start by soldering the smallest parts first: resistors, diodes, capacitors and regulators - take note of the direction on the diodes - black bar on component matching black bar on footprint
- Next lets do the ic’s/sockets - make sure the direction is correct! place in and fold two corner pins to hold in place, then solder all pins. you can place the ic in now too
- Now lets do the micro-controller and usb-host-shield -if you want to be able to remove them from the board you will need to solder header sockets to the board first – otherwise can directly solder the header pins
- for the usb-host-shield right_row I would do a 1x2 header horizontally at the top to catch that 5v pin and then 1x11 row vertically for the rest – the left_row can just be a single 1x12 vertical header
- Finally place the interface parts (eg jacks and sockets) be generous with the solder here -> this is to strengthen the mechanical connections as well as making electrical ones
- Leave j8 header unpopulated – this just exposes the bootloader pins so firmware can be reset in the rare case that the pro-micro gets bricked – also leave j1 header unpopulated unless you want to power from a euro-power-header

# CREDITS AND MORE INFO

This circuit is distributed through UNDERSCORES – open video hardware label – visit underscores.shop for more info

The pcb was designed using KICAD , this booklet was created in LibreOffice Draw

Everything from gerbers, cad files, panels and documentation is freely available online and distributed under CC-BY-SA / open-source licenses – help us contribute to the commons !

Ask any questions or start discussions related to this project on the scanlines.xyz forum – an online community space dedicated to diy av / electronic media art

You can contact me directly at tim (at) cyberboy666 (dot) com Please get in touch if you are interested in hosting a workshop !

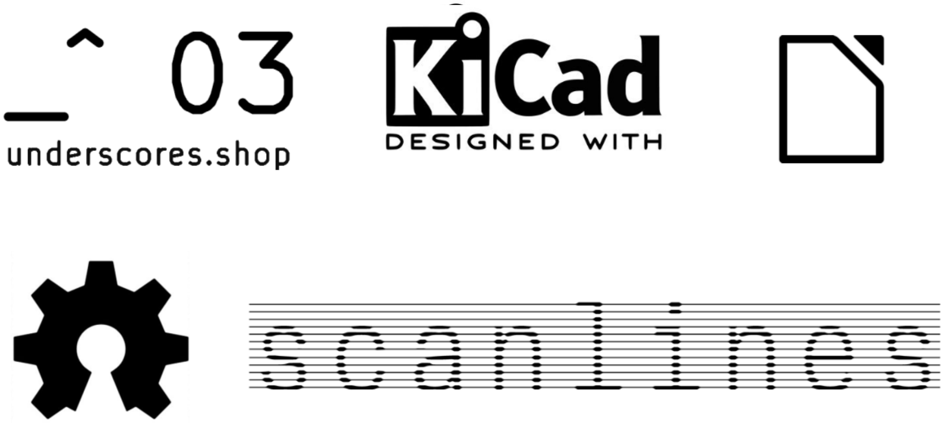
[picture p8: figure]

Thanks to Gilbert Sinnott for helping with initial experiments. to Bastien Lavaud for circuit advice, always. To Ben Caldwell for project advice. To everyone who has or will contribute ♥♥♥

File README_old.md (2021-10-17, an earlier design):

# WIP _transcribe_

for midi control of panasonic video mixers.

__disclaimer__ _this project is a work in progress. dont order any boards or expect things to be clear or make sense just yet. if you would like to help or test however pls email me : langolierz@gmail.com_

## background

some people in the video-art community are performing with old hardware video-mixers such as in the Pansonic_WJ_AVE and Pansonic_WJ_MX lines. some of these mixers have a RS232 serial for interfacing with them digitally. this is especially useful for live performace where sequencing can assist physical actions. there are some cool examples of software specifically written to interface with these mixers (such as [Freds excel app](https://a2m2.ch/fred/wj-ave55.htm) and  [Klifs MaxPatch](https://vimeo.com/161662975) ) , but many more programs and devices that are made to interface digitally using MIDI.

the aim of this project is to create a small utility module that can __\_transcribe\___ _MIDI_, a protocal used commonly in live/performance instruments to the specific _RS232 panasonic video-mixer spec_ , to better equipt these retired workstations for their new life of glamour on stage

## supported video-mixers:

- panasonic wj_ave55 wip
- (not yet) panasonic wj_mx20
- (not yet) panasonic wj_mx30
- (not yet) panasonic wj_mx50
- (not yet) panasonic wj_mx70
- more ? if you have another mixer or any old equipment with rs232 (or maybe rs422 - i dunno yet..) and a spec-sheet maybe we can add support for it ?

## hardware features

- input USB-midi from a USB-HOST such as a computer or rpi
- input serial-midi from older midi devices (din)
- input USB-midi for a USB-DEVICE such as a korg nanokontroller or otherwise
- output RS232-serial commands to control panasonic video-mixers
- all these interfaces are bi-directional and so can be modified with firmware to do other useful things (eg like a USB-DEVICE -> SERIAL converter)

## software features

- mapping of notes or cc presses to commands (BUTTON)
- mapping of cc values to continous controls, like a-b mix or key-amount (SLIDER)
- mapping of two cc channels to 2d continous controls like xy-position or colour-select (JOYSTICK)
- mapping of notes or cc presses to alternating commands (SWITCH)
- mapping of notes or cc presses to a rotating selection of consecutive commands (CYCLE)
- mapping of cc values to a partitioned selection of consecutive commands (STEP)

(extenable to more such as random, random-walks, ossilators etc ...?)

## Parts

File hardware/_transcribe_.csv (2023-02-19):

Reference | Quantity | Value | Footprint | Datasheet
C1 | 1 | 100uf | Capacitor_THT:CP_Radial_D5.0mm_P2.50mm
C2 C3 C4 C5 | 4 | 0.1u | Capacitor_THT:C_Disc_D4.3mm_W1.9mm_P5.00mm
D1 D2 | 2 | 1N4148 | Diode_THT:D_T-1_P5.08mm_Horizontal
J1 | 1 | europower | lib_fp:PinHeader_2x08_P2.54_Euro
J2 J4 J6 | 3 | stereo_jack_3.5mm | lib_fp:horizontal_3.5mm_stereo_TRS_jack_A-853
J3 | 1 | dsub9_socket | lib_fp:tht_DSUB-9_Vertical_Tayda | ~
J5 J7 | 2 | din5 | lib_fp:horizontal_din5-A1010 | http://www.mouser.com/ds/2/18/40_c091_abd_e-75918.pdf
J8 | 1 | bootloader | Connector_PinSocket_2.54mm:PinSocket_1x06_P2.54mm_Vertical
J9 J10 | 2 | jumper | Connector_PinHeader_2.54mm:PinHeader_1x03_P2.54mm_Vertical
R1 R2 R3 | 3 | 220 | Resistor_THT:R_Axial_DIN0207_L6.3mm_D2.5mm_P5.08mm_Vertical
R4 | 1 | 10k | Resistor_THT:R_Axial_DIN0207_L6.3mm_D2.5mm_P5.08mm_Vertical
SW1 | 1 | SW_Push_Dual | Button_Switch_THT:SW_PUSH_6mm_H7.3mm
U1 | 1 | ProMicro | lib_fp:tht_ProMicro
U2 | 1 | MAX232 | Package_DIP:DIP-16_W7.62mm | http://www.ti.com/lit/ds/symlink/max232.pdf
U3 | 1 | 6N137 | Package_DIP:DIP-8_W7.62mm | https://optoelectronics.liteon.com/upload/download/DS70-2008-0032/6N135-L%206N136-L%20series.pdf
U4 | 1 | CD4069 | Package_DIP:DIP-14_W7.62mm | http://www.intersil.com/content/dam/Intersil/documents/cd40/cd4069ubms.pdf
U5 | 1 | usbHostMini | lib_fp:tht_usbHostMidi
U6 | 1 | 78L33 | Package_TO_SOT_THT:TO-92_HandSolder | http://www.st.com/content/ccc/resource/technical/document/datasheet/15/55/e5/aa/23/5b/43/fd/CD00000446.pdf/files/CD00000446.pdf/jcr:content/translations/en.CD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

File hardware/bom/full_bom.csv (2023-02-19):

sku | qty | ref | val | vendor
A-959 | 1 | C1 | 100uf | tayda
A-4008 | 4 | C2 C3 C4 C5 | 0.1u | tayda
A-157 | 2 | D1 D2 | 1N4148 | tayda
A-2956 | 1 | J1 | europower | tayda
A-853 | 3 | J2 J4 J6 | stereo_jack_3.5mm | tayda
A-300 | 1 | J3 | dsub9_socket | tayda
A-1010 | 2 | J5 J7 | din5 | tayda
- | 1 | J8 | bootloader | -
A-1324 | 2 | J9 J10 | jumper | tayda
A-2246 | 3 | R1 R2 R3 | 220 | tayda
A-2203 | 1 | R4 | 10k | tayda
A-5129 | 1 | SW1 | SW_Push_Dual | tayda
https://www.aliexpress.com/item/32846843498.html | 1 | U1 | ProMicro | other
A-034 | 1 | U2 | MAX232 | tayda
A-871 | 1 | U3 | 6N137 | tayda
A-882 | 1 | U4 | CD4069 | tayda
https://www.aliexpress.com/item/32881871223.html | 1 | U5 | usbHostMini | other
A-492 | 1 | U6 | 78L33 | tayda

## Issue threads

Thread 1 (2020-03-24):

proto-pcb improvements:

langolierz, 2020-03-24:
- the din-midi sockets from tayda are larger than the footprint implied -> looks like they wont currently fit without removing some of the plastic first
-the dsub sockets from tayda dont fit the footprint - holes are too small , and also spacing seems a little different ...
- capicitor footprint is a little too tight, and too close if the dsub did fit
- ~~wrong way footprint for u6 -> flat part should be facing the hostshield (this footprint is a lil small too)~~ , ~~actually looks like the datasheet is. wrong~~
- it is not obvious which way the euro header should go !
- no diodes to protect if usb (arduino and euro powered together)

langolierz, 2020-03-25:
- also should change so both plains are ground and run a trace for +5 ...

langolierz, 2020-03-28:
looks like the midi out buffers are backwards ?

langolierz, 2020-03-29:
all these things are fixed now, will wait a little while for any more feedback before ordering v0.2

langolierz, 2020-04-24:
want to also at breakout pins for spi/rst to the micro so it can be reflashed more easily while soldered to the board

langolierz, 2020-06-13:
updated to include bootloader breakout

Closed 2020-06-13.

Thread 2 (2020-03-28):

firmware improvements

cyberboy666, 2020-03-28:
- ~~try using platformio~~
- ~~set up a channel (2-3 ?) for a flat, fixed, mapping of all the commands (maybe with a bool switch in the code)~~
- set up main channel 1 for custom mapping ; default for korg nanokontroller
- ~~ensure the 2, and 3d commands are working with stored values~~
- examples / some docs about special mappings eg - steps, switches, toggles etc
- ?very simple example of an oscillator function, random function and tap-tempo ?

langolierz, 2020-03-29:
there is also the problem of korgnanocontrol sending cc0 as note_off ...

Closed 2022-04-06.

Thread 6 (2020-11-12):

hardware improvements

cyberboy666, 2020-11-12:
- mounting holes
- more space between midi connectors
- remove euroheader or ensure there is space on the top for usb host board too
- resistor spacing too tight
- horozontal dsub ?

Closed 2022-04-06.

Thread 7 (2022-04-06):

investigate a version that (also/alternatively) supports rs422

cyberboy666, 2022-04-06:
panasonic mx20 doesnt have rs232 serial but it does take rs422 serial...

so the circuit would have to support this protocol also/instead to control this mixer..

for rs422/485 it seems like a [max485 chip](https://www.taydaelectronics.com/max485epa-max485-rs-485-rs-422-transceiver-ic.html) would do it - combined with a few more resistors:

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

the current form-factor would only support one or the other - however maybe best to consider a (larger) upgrade that has footprints for both (or some kind of extension board for rs422? )

cyberboy666, 2022-06-22:
iv decided to experiment with a fork of this project that replaces the max232 ic and surrounding circuitry with this max485 ic (and surrounding circuitry)...

keeping the same formfactor and input circuit as mainline...

if this works well and proves to be useful i will from here consider a merge into mainline - in the form a circuit revision that allows rs422 integration somehow...

work on this fork can be found on this [_transcribe_RS422-fork](https://github.com/cyberboy666/_transcribe_RS422-fork)

some things still to decide is what socket / pinout to implement for this fork:

https://electronics.stackexchange.com/questions/63914/standard-pinout-for-rs-422 - some info about rs422 over dsub9

panasonic mx50 can take rs232 and rs422 over dsub9 so would be worth considering matching this pinout.

panasonic mx20 takes rs422 over mini-din8 - maybe i should consider this as an option also ? (and ofcourse whether to keep outputing over 3.5mm stereo jack also)

cyberboy666, 2022-06-22:
from mx50 manual:

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

from mx20 manual:

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

cyberboy666, 2022-06-22:
if i was to include mini-din8 socket for mx30 on pcb it would use a part like this:

https://nz.mouser.com/ProductDetail/CUI-Devices/MD-80SV?qs=WyjlAZoYn523OJ7YijknOg%3D%3D

this is vertical mount - not sure what would use if wanting to horizontal mount....

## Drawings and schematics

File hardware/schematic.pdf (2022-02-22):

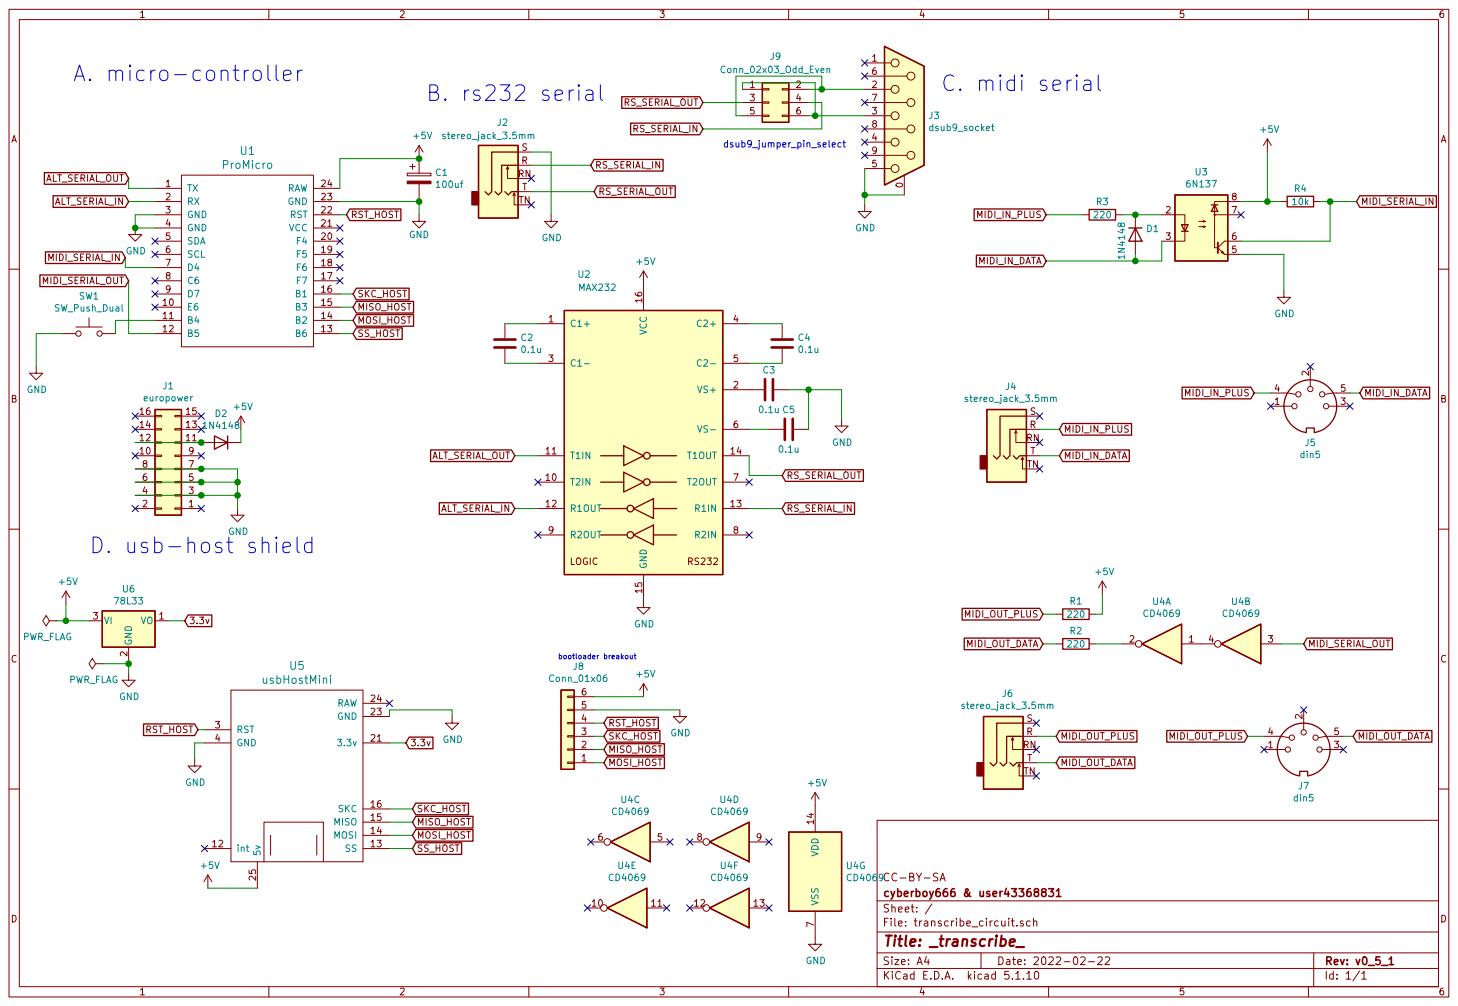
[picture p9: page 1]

bootloader breakout A. micro-controller

File: transcribe_circuit.sch Sheet: / cyberboy666 & user43368831 CC-BY-SA

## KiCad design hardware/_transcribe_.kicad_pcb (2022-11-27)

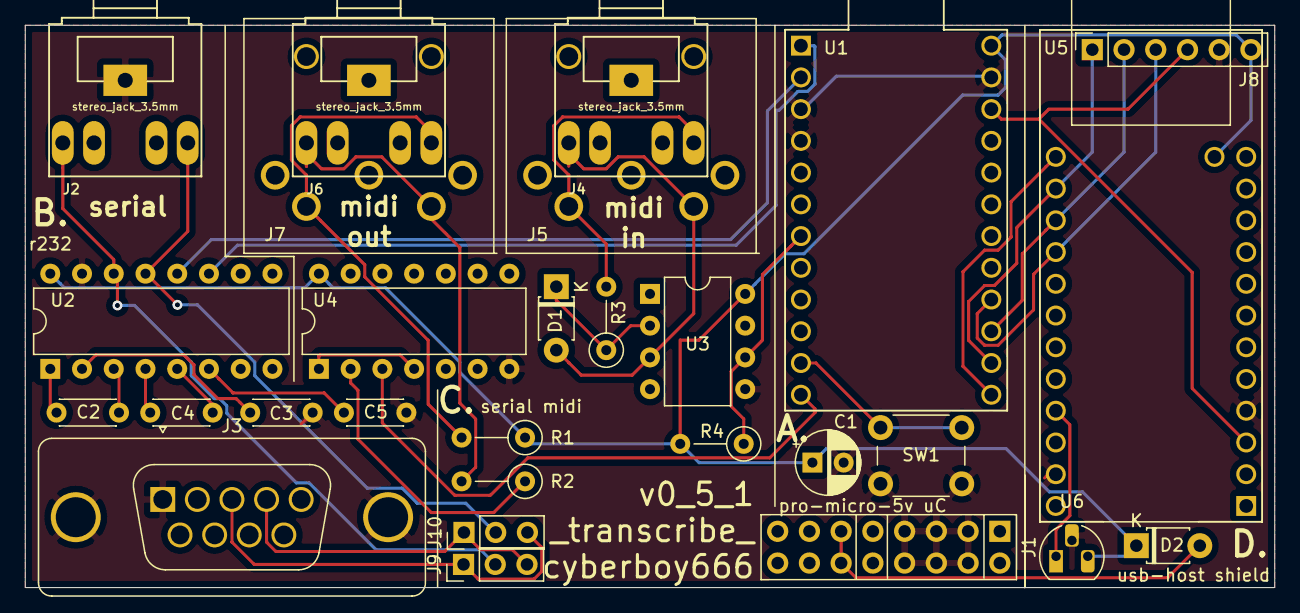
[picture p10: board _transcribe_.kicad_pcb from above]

Board: 2 copper layers, 100.0 x 45.0 mm, 28 parts (0 on the bottom side), 31 nets.

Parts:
C1: 100uf; CP_Radial_D5.0mm_P2.50mm
C2, C3, C4, C5: 0.1u; C_Disc_D4.3mm_W1.9mm_P5.00mm
D1, D2: 1N4148; D_T-1_P5.08mm_Horizontal
J1: europower; PinHeader_2x08_P2.54_Euro
J2, J4, J6: stereo_jack_3.5mm; horizontal_3.5mm_stereo_TRS_jack_A-853
J3: dsub9_socket; tht_DSUB-9_Vertical_Tayda
J5, J7: din5; horizontal_din5-A1010
J8: bootloader; PinSocket_1x06_P2.54mm_Vertical
J9, J10: jumper; PinHeader_1x03_P2.54mm_Vertical
R1, R2, R3: 220; R_Axial_DIN0207_L6.3mm_D2.5mm_P5.08mm_Vertical
R4: 10k; R_Axial_DIN0207_L6.3mm_D2.5mm_P5.08mm_Vertical
SW1: SW_Push_Dual; SW_PUSH_6mm_H7.3mm
U1: ProMicro
U2: MAX232; DIP-16_W7.62mm
U3: 6N137; DIP-8_W7.62mm
U4: CD4069; DIP-14_W7.62mm
U5: usbHostMini; usbHostMidi
U6: 78L33; TO-92_HandSolder

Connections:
3.3v: U5.21, U6.1
+5V: C1.1, D2.1, J8.6, R1.1, R4.2, U1.24, U2.16, U3.8, U4.14, U5.25, U6.3
ALT_SERIAL_IN: U1.2, U2.12
ALT_SERIAL_OUT: U1.1, U2.11
GND: C1.2, C3.1, C5.1, J1.3, J1.4, J1.5, J1.6, J1.7, J1.8, J2.S, J3.0, J3.5, J8.5, SW1.1, U1.3, U1.4, U1.23, U2.15, U3.5, U4.7, U5.4, U5.23, U6.2
MIDI_IN_DATA: D1.2, J4.T, J5.5, U3.3
MIDI_IN_PLUS: J4.R, J5.4, R3.2
MIDI_OUT_DATA: J6.T, J7.5, R2.2
MIDI_OUT_PLUS: J6.R, J7.4, R1.2
MIDI_SERIAL_IN: R4.1, U1.7, U3.6
MIDI_SERIAL_OUT: U1.12, U4.3
MISO_HOST: J8.2, U1.15, U5.15
MOSI_HOST: J8.1, U1.14, U5.14
unnamed: C2.1, U2.1
unnamed: C2.2, U2.3
unnamed: C3.2, U2.2
unnamed: C4.1, U2.4
unnamed: C4.2, U2.5
unnamed: C5.2, U2.6
unnamed: D1.1, R3.1, U3.2
unnamed: D2.2, J1.11, J1.12
unnamed: J3.2, J9.3, J10.1
unnamed: J3.3, J9.1, J10.3
unnamed: R2.1, U4.2
unnamed: SW1.2, U1.11
unnamed: U4.1, U4.4
RST_HOST: J8.4, U1.22, U5.3
RS_SERIAL_IN: J2.R, J10.2, U2.13
RS_SERIAL_OUT: J2.T, J9.2, U2.14
SKC_HOST: J8.3, U1.16, U5.16
SS_HOST: U1.13, U5.13

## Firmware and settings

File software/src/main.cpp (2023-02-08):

#include <usbh_midi.h>
#include <usbhub.h>
#include <SPI.h>
#include <usbmidi.h>
#include "midievents.h"
#include "commands.h"
#include <AltSoftSerial.h>
#include "OneButton.h"


OneButton button1(A8, true);
AltSoftSerial altSerial;
USB Usb;
USBH_MIDI  Midi(&Usb);
uint16_t pid, vid;
char cmd[14] = {};
uint8_t notes[128];
uint8_t cc[128];
uint8_t midiCommand, midiChannel, midiParam1, midiParam2;
uint8_t position;
bool hasUsbDevice = 0;
bool dropZeroCC;
bool showHasUsbDevice = 0;
unsigned long time_now = 0;


uint8_t switchStore[20];
uint8_t paramStore[127];

int incomingByte = 0; // for incoming serial data

bool useFlatMidiMap;

bool flip = false;

bool readInputFromMidiDevice();
bool readInputFromMidiHost();
bool readInputFromMidiSerial();
void connect_usb_midi();
void logUsbDeviceStatus();
void logMessageToSerial();

void setCmd(char* inputCmd, uint8_t inputParam = 0);
void setCmdNoReplace(char* inputCmd);
void setCmdSwitch(char* inputCmd1, char* inputCmd2, uint8_t switchIndex);
void setCmdToggleAVE55(char* inputCmd, uint8_t start, uint8_t offset, uint8_t switchIndex);
void setCmdStepAVE55(char* inputCmd, uint8_t param, uint8_t start, uint8_t offset);

void setCmdToggleMX50(char* inputCmd, uint8_t maxValue, uint8_t switchIndex);
void setCmdStepMX50(char* inputCmd, uint8_t param, uint8_t maxValue);
void setCmdParamRandom(char* inputCmd);



void setDelugeExtronMap(){

  if(midiCommand == MIDICOMMAND::NOTEON){
    if(midiParam1 == 60){setCmdNoReplace(EXTRON_MAV_1x1);}
    else if(midiParam1 == 62){setCmdNoReplace(EXTRON_MAV_1x2);}
    else if(midiParam1 == 64){setCmdNoReplace(EXTRON_MAV_1x3);}
    else if(midiParam1 == 65){setCmdNoReplace(EXTRON_MAV_2x1);}
    else if(midiParam1 == 67){setCmdNoReplace(EXTRON_MAV_2x2);}
    else if(midiParam1 == 69){setCmdNoReplace(EXTRON_MAV_2x3);}
    else if(midiParam1 == 71){setCmdNoReplace(EXTRON_MAV_3x1);}
    else if(midiParam1 == 72){setCmdNoReplace(EXTRON_MAV_3x2);}
    else if(midiParam1 == 74){setCmdNoReplace(EXTRON_MAV_3x3);}
  }
}

void setAVE55nanokontrolMap(){

  if(midiCommand == MIDICOMMAND::NOTEON){
    // put note commands here
  }
  else if(midiCommand == MIDICOMMAND::CC){
    // slider row:
    if(midiParam1 == 0){setCmd(A55_A_B_MIX_LEVEL, midiParam2);}
    else if(midiParam1 == 1){setCmd(A55_THRESHOLD_LUM_KEY, midiParam2);}
    else if(midiParam1 == 2){setCmd(A55_CENTER_WIPE_X, midiParam2);}
    else if(midiParam1 == 3){setCmd(A55_CENTER_WIPE_Y, midiParam2);}
    else if(midiParam1 == 4){setCmd(A55_SCENE_GRABER_X, midiParam2);}
    else if(midiParam1 == 5){setCmd(A55_SCENE_GRABER_Y, midiParam2);}
    else if(midiParam1 == 6){setCmd(A55_COLOR_CORECT_X, midiParam2);}
    else if(midiParam1 == 7){setCmd(A55_COLOR_CORECT_Y, midiParam2);}

    // knob row
    else if(midiParam1 == 16){setCmdStepAVE55(A55_A_BUS_STROBO_OFF, midiParam2, 70, 6);}
    else if(midiParam1 == 17){setCmdStepAVE55(A55_A_BUS_MOSAIC_OFF, midiParam2, 76, 6);}
    else if(midiParam1 == 18){setCmdStepAVE55(A55_A_BUS_PAINT_OFF, midiParam2, 82, 6);}
    // else if(midiParam1 == 19){setCmdStepAVE55(A55_A_BUS_PAINT_OFF, midiParam2, 82, 6);}
    else if(midiParam1 == 20){setCmdStepAVE55(A55_B_BUS_STROBO_OFF, midiParam2, 94, 6);}
    else if(midiParam1 == 21){setCmdStepAVE55(A55_B_BUS_MOSAIC_OFF, midiParam2, 100, 6);}
    else if(midiParam1 == 22){setCmdStepAVE55(A55_B_BUS_PAINT_OFF, midiParam2, 106, 6);}
    // else if(midiParam1 == 23){setCmdStepAVE55(A55_A_BUS_PAINT_OFF, midiParam2, 82, 6);}

    // top row buttons (S)
    else if(midiParam1 == 32){setCmdToggleAVE55(A55_WIPE_SQUARE_CORNER_UL, 1, 16, 0);}
    else if(midiParam1 == 33){setCmdToggleAVE55(A55_WIPE_SQUARE, 17, 7, 9);}
    else if(midiParam1 == 34){setCmdToggleAVE55(A55_DIRECTION_ONE_WAY, 40, 2, 2);}
    else if(midiParam1 == 35){setCmdParamRandom(A55_A_B_MIX_LEVEL);}
    // else if(midiParam1 == 36){setCmdToggleAVE55(A55_WIPE_SQUARE_CORNER_UL, 1, 16, 0);}
    // else if(midiParam1 == 37){setCmdToggleAVE55(A55_WIPE_SQUARE, 17, 7, 9);}
    // else if(midiParam1 == 38){setCmdToggleAVE55(A55_DIRECTION_ONE_WAY, 40, 2, 2);}
    // else if(midiParam1 == 39){setCmdParamRandom(A55_A_B_MIX_LEVEL);}
    
    // middle row buttons (M)
    else if(midiParam1 == 48){setCmd(A55_WIPE_MIX_BUTTON);}
    else if(midiParam1 == 49){setCmd(A55_LUM_KEY);}
    else if(midiParam1 == 50){setCmdToggleAVE55(A55_A_BUS_EFFECT_ON, 180, 2, 5);}
    else if(midiParam1 == 51){setCmdToggleAVE55(A55_B_BUS_EFFECT_ON, 182, 2, 6);}
    else if(midiParam1 == 52){setCmdToggleAVE55(A55_A_BUS_NEGATIVE_OFF, 87, 2, 3);}
    else if(midiParam1 == 53){setCmdToggleAVE55(A55_B_BUS_NEGATIVE_OFF, 111, 2, 4);}
    else if(midiParam1 == 54){setCmdToggleAVE55(A55_B_BUS_COLOR_CORRECTOR_OFF, 115, 2, 7);}
    else if(midiParam1 == 55){setCmdToggleAVE55(A55_A_BUS_COLOR_CORRECTOR_OFF, 91, 2, 8);}

    // bottom row buttons (R)
    else if(midiParam1 == 64){setCmd(A55_A_BUS_SOURCE_1);}
    else if(midiParam1 == 65){setCmd(A55_A_BUS_SOURCE_2);}
    else if(midiParam1 == 66){setCmd(A55_A_BUS_SOURCE_3);}
    else if(midiParam1 == 67){setCmd(A55_A_BUS_SOURCE_4);}
    else if(midiParam1 == 68){setCmd(A55_B_BUS_SOURCE_1);}
    else if(midiParam1 == 69){setCmd(A55_B_BUS_SOURCE_2);}
    else if(midiParam1 == 70){setCmd(A55_B_BUS_SOURCE_3);}
    else if(midiParam1 == 71){setCmd(A55_B_BUS_SOURCE_4);}
  }
}

void setMX50nanokontrolMap(){

  if(midiCommand == MIDICOMMAND::NOTEON){
    // put note commands here
  }
  else if(midiCommand == MIDICOMMAND::CC){
    // slider row:
    if(midiParam1 == 0){setCmd(MX50_A_B_MIX_LEVEL, midiParam2);}
    else if(midiParam1 == 1){setCmd(MX50_THRESHOLD_LUM_KEY, midiParam2);}
    else if(midiParam1 == 2){setCmd(MX50_CENTER_WIPE_X, midiParam2);}
    else if(midiParam1 == 3){setCmd(MX50_CENTER_WIPE_Y, midiParam2);}
    else if(midiParam1 == 4){setCmd(MX50_KEY_SLICE, midiParam2);}
    // else if(midiParam1 == 5){setCmd(MX50_SCENE_GRABER_Y, midiParam2);}
    // else if(midiParam1 == 6){setCmd(MX50_COLOR_CORECT_X, midiParam2);}
    // else if(midiParam1 == 7){setCmd(MX50_COLOR_CORECT_Y, midiParam2);}

    // knob row
    else if(midiParam1 == 16){setCmd(MX50_COLOR_CORRECT_X, midiParam2);}
    else if(midiParam1 == 17){setCmd(MX50_COLOR_CORRECT_Y, midiParam2);}
    else if(midiParam1 == 18){setCmd(MX50_COLOR_CORRECT_GAIN, midiParam2);}
    // else if(midiParam1 == 19){setCmd(MX50_B_BUS_COLOR_CORRECT_Y, midiParam2);}

    else if(midiParam1 == 20){setCmdStepMX50(MX50_STROBO, midiParam2, 62);}
    else if(midiParam1 == 21){setCmdStepMX50(MX50_MOSAIC, midiParam2, 30);}
    else if(midiParam1 == 22){setCmdStepMX50(MX50_PAINT, midiParam2, 7);}
    // else if(midiParam1 == 23){setCmdStepAVE55(A55_A_BUS_PAINT_OFF, midiParam2, 82, 6);}

    // top row buttons (S)

    else if(midiParam1 == 32){setCmdSwitch(MX50_A_BUS_COLOR_CORRECT_ON, MX50_A_BUS_COLOR_CORRECT_OFF, 0);}
    else if(midiParam1 == 33){setCmdSwitch(MX50_B_BUS_COLOR_CORRECT_ON, MX50_B_BUS_COLOR_CORRECT_OFF, 1);}
    else if(midiParam1 == 34){setCmdSwitch(MX50_SCENE_GRABER_ON, MX50_SCENE_GRABER_OFF, 2);}
    else if(midiParam1 == 35){setCmdParamRandom(MX50_A_B_MIX_LEVEL);}
    else if(midiParam1 == 36){setCmd(MX50_A_BUS_STROBO_OFF);}
    else if(midiParam1 == 37){setCmd(MX50_A_BUS_MOSAIC_OFF);}
    else if(midiParam1 == 38){setCmd(MX50_A_BUS_PAINT_OFF);}
    else if(midiParam1 == 39){setCmdToggleMX50(MX50_WIPE, 40, 5);}
    
    // middle row buttons (M)
    // else if(midiParam1 == 48){setCmd(A55_WIPE_MIX_BUTTON);}
    // else if(midiParam1 == 49){setCmd(MX50_WIPE_NUMBER);}
    else if(midiParam1 == 50){setCmdSwitch(MX50_A_BUS_EFFECT_ON, MX50_A_BUS_EFFECT_OFF, 3);}
    else if(midiParam1 == 51){setCmdSwitch(MX50_B_BUS_EFFECT_ON, MX50_B_BUS_EFFECT_OFF, 4);}
    else if(midiParam1 == 52){setCmd(MX50_A_BUS_NEGATIVE_OFF);}
    else if(midiParam1 == 53){setCmd(MX50_A_BUS_NEGATIVE_ON);}
    else if(midiParam1 == 54){setCmd(MX50_B_BUS_NEGATIVE_OFF);}
    else if(midiParam1 == 55){setCmd(MX50_B_BUS_NEGATIVE_ON);}

    // bottom row buttons (R)
    else if(midiParam1 == 64){setCmd(MX50_A_BUS_SOURCE_1);}
    else if(midiParam1 == 65){setCmd(MX50_A_BUS_SOURCE_2);}
    else if(midiParam1 == 66){setCmd(MX50_A_BUS_SOURCE_3);}
    else if(midiParam1 == 67){setCmd(MX50_A_BUS_SOURCE_4);}
    else if(midiParam1 == 68){setCmd(MX50_B_BUS_SOURCE_1);}
    else if(midiParam1 == 69){setCmd(MX50_B_BUS_SOURCE_2);}
    else if(midiParam1 == 70){setCmd(MX50_B_BUS_SOURCE_3);}
    else if(midiParam1 == 71){setCmd(MX50_B_BUS_SOURCE_4);}
  }
}

void setup(){
  altSerial.begin(31250);
  Serial.begin(9600);
  Serial1.begin(9600, SERIAL_8N1); // use SERIAL_7O1 for mx50, ,default (SERIAL_8N1) for kramer, ave55 and extron // 
  button1.attachClick(connect_usb_midi);

  hasUsbDevice = false;
  vid = pid = 0;
  switchStore[2] = {};
  useFlatMidiMap = true;
  dropZeroCC = true; // to ignore 'note_off' cc messages

  connect_usb_midi();

}

void loop(){
  button1.tick();
  logUsbDeviceStatus();
  midiCommand = midiChannel = midiParam1 = midiParam2 = 0;
  position = 0;
  memset(&cmd[0], 0, sizeof(cmd));
  bool hasMessage = false;

  if(hasUsbDevice){hasMessage = readInputFromMidiDevice();} // check from the usbhost-sheild first if connected
  if(!hasMessage){hasMessage = readInputFromMidiHost();} // if nothing check the usb on the arduino
  if(!hasMessage){hasMessage = readInputFromMidiSerial();} // if still nothing check the serial port  
  if(!hasMessage){return;}

  if(midiCommand == 0){return;}
 // ignore cc note_off messages (at cost of no zero on slider)
  if(midiCommand == MIDICOMMAND::CC && midiParam2 == 0 && dropZeroCC){return;} 

  if(midiChannel == 0){setAVE55nanokontrolMap();}

  logMessageToSerial();


  if(cmd[0] == 0){return;}
  Serial1.write(2);
  Serial1.write(cmd);
  Serial1.write(3);

}

bool readInputFromMidiDevice(){
  Usb.Task();
  char buf[20];
  uint8_t bufMidi[3];
  uint16_t  rcvd;

  if (Midi.RecvData( &rcvd,  bufMidi) == 0 ) {
    uint8_t first =  bufMidi[1];
    midiCommand = first & 0xF0;
    midiChannel = first & 0xF;
    midiParam1 = bufMidi[2];
    midiParam2 = bufMidi[3];
    return true;
    }
  return false;
}

bool readInputFromMidiHost(){

  USBMIDI.poll();
  if(USBMIDI.available()){
    //Skip to beginning of next message (silently dropping stray data bytes)
    while(!(USBMIDI.peek() & 0x80)) USBMIDI.read();

    uint8_t first = USBMIDI.read();

    midiCommand = first & 0xF0; // command
    midiChannel = first & 0xF; // channel
    midiParam1 = USBMIDI.read(); // param 1 (note)
    midiParam2 = USBMIDI.read(); // param 2 (value)

    altSerial.write(first);
    altSerial.write(midiParam1);
    altSerial.write(midiParam2);

    USBMIDI.flush();
    return true;
  }
  return false;
}

bool readInputFromMidiSerial(){

  if(altSerial.available() < 3){ return false;}
  //Skip to beginning of next message (silently dropping stray data bytes)
  while(!(altSerial.peek() & 0x80)){ altSerial.read(); }
  if(altSerial.available() < 3){ return false;}
  uint8_t first = altSerial.read();

  midiCommand = first & 0xF0; // command 0b11110000 = 0xF0
  midiChannel = first & 0xF; // channel 0b00001111 = 0xF
  midiParam1 = altSerial.read(); // param 1
  midiParam2 = altSerial.read(); // param 2

  // altSerial.flush();
  while(altSerial.available()){altSerial.read();}

  return true;
}

void setCmd(char* inputCmd, uint8_t inputParam){

  // Serial.print(inputCmd);
  // Serial.print("<-- input command\n");
  strcpy(cmd, inputCmd);

  // replace special chars in serial message
  for (uint8_t i = 0; i < 11; i++){
    if(cmd[i] == 0x00 || cmd[i+1] == 0x00){ return; }

    if(cmd[i] == '~' && cmd[i+1] == '0'){
      // replace with midi param -> dont save in store
      char hexParam[4] = {};
      sprintf(hexParam, "%02X", inputParam*2);
      cmd[i] = hexParam[0];
      cmd[i+1] = hexParam[1];
    }
    if(cmd[i] == '~' && cmd[i+1] != '0'){
      // replace with midi param and save to store
      paramStore[int(cmd[i+1])] = inputParam*2;

      char hexParam[4] = {};
      sprintf(hexParam, "%02X", inputParam*2);
      cmd[i] = hexParam[0];
      cmd[i+1] = hexParam[1];
    }
    if(cmd[i] == '*'){
      // replace with store param

      char hexParam[4] = {};
      sprintf(hexParam, "%02X", paramStore[int(cmd[i+1])]);
      cmd[i] = hexParam[0];
      cmd[i+1] = hexParam[1];
    }

  }

}

void setCmdNoReplace(char* inputCmd){

  Serial.print(inputCmd);
  Serial.print("<-- input command\n");
  strcpy(cmd, inputCmd);

}

void setCmdSwitch(char* inputCmd1, char* inputCmd2, uint8_t switchIndex){
  if(switchStore[switchIndex] == 0){setCmd(inputCmd1); }
  else{ setCmd(inputCmd2); }
  switchStore[switchIndex] = (switchStore[switchIndex] + 1) % 2;
}

void setCmdToggleAVE55(char* inputCmd, uint8_t start, uint8_t offset, uint8_t switchIndex){
  int value = start + switchStore[switchIndex];
  char charValue[6] = {};
  sprintf(charValue, "%03d", value);
  // this is hardcoded to replace a 3digit number at the 4th in command
  // need to refactor this if using differnt cmds to this
  inputCmd[4] = charValue[0];
  inputCmd[5] = charValue[1];
  inputCmd[6] = charValue[2];

  setCmd(inputCmd);
  switchStore[switchIndex] = (switchStore[switchIndex] + 1) % offset;
}

void setCmdStepAVE55(char* inputCmd, uint8_t param, uint8_t start, uint8_t offset){
  int value = start + ( (param * offset) / 128 );
  char charValue[6] = {};
  sprintf(charValue, "%03d", value);
  // this is hardcoded to replace a 3digit number at the 4th in command
  // need to refactor this if using differnt cmds to this
  inputCmd[4] = charValue[0];
  inputCmd[5] = charValue[1];
  inputCmd[6] = charValue[2];


  setCmd(inputCmd);
}

void setCmdParamRandom(char* inputCmd){
  uint8_t randNumber = random(1,128);
  setCmd(inputCmd, randNumber);
}

void setCmdStepMX50(char* inputCmd, uint8_t param, uint8_t maxValue){
  strcpy(cmd, inputCmd);
  char maxHex[6] = {};
  sprintf(maxHex, "%X", maxValue+1);
  int maxHexSize = 0;
  for (uint8_t i = 0; i < 6; i++){
    if(maxHex[i] != 0 ){maxHexSize++;}
  }
  int value = (param * maxValue) / 128;
  char valueHex[6] = {};

  if(maxHexSize == 1){ sprintf(valueHex, "%1X", value);}
  else if(maxHexSize == 2){sprintf(valueHex, "%02X", value);}
  else{sprintf(valueHex, "%X", value);}

  for(uint8_t i = 0; i < 11; i++){
    if(cmd[i] == '~' ){
      for(uint8_t j=0; j < 6; j++){
        if(valueHex[j] != 0){cmd[i+j] = valueHex[j];}
      }
    }
  }

setCmd(cmd);
}

void setCmdToggleMX50(char* inputCmd, uint8_t maxValue, uint8_t switchIndex){
  strcpy(cmd, inputCmd);
  char valueChar[4] = {};
  sprintf(valueChar, "%02d", switchStore[switchIndex]);
  for(uint8_t i = 0; i < 11; i++){
    if(cmd[i] == '~' ){
      for(uint8_t j=0; j < 4; j++){
        if(valueChar[j] != 0){cmd[i+j] = valueChar[j];}
      }
    }
  }

  switchStore[switchIndex] = (switchStore[switchIndex] + 1) % maxValue; 
}

void logMessageToSerial(){
  Serial.print(midiParam1);
  Serial.print("<-note (midiParam1)\n");
  Serial.print(midiChannel);
  Serial.print("<-channel  (midiChannel)\n");
  Serial.print(midiCommand);
  Serial.print("<-command (midiCommand)\n"); 
  // midiParam2 = midiParam2 - 64; // weird off by 64 bug ??
  Serial.print(midiParam2);
  Serial.print("<-value (midiParam2)\n\n");

  // write the command to serial port
  Serial.print("\n");
  Serial.print(cmd);
  Serial.print("<-cmd\n");
}

void connect_usb_midi() {
  Serial.println("Button 1 click.");
    if (Usb.Init() == 0){ // means it is successful
      hasUsbDevice = true;
    }
  showHasUsbDevice = 1;
  time_now = millis();
} // click1

void logUsbDeviceStatus(){
  if(showHasUsbDevice && millis() > time_now + 400){
    Serial.print(Midi.GetAddress() != 0);
    Serial.print("<--attached device\n");
    showHasUsbDevice = 0;
    time_now = 0;
  }
}

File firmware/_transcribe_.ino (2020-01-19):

#include <usbh_midi.h>
#include <usbhub.h>
#include <SPI.h>
#include <usbmidi.h>
#include "src/midievents.h"
#include "src/commands.h"
#include <AltSoftSerial.h>

AltSoftSerial altSerial;
USB Usb;
USBH_MIDI  Midi(&Usb);
uint16_t pid, vid;
char cmd[12] = {};
uint8_t cmdNum = -1;
uint8_t notes[128];
uint8_t cc[128];
uint8_t midiCommand, midiChannel, midiParam1, midiParam2;
bool hasUsbDevice;

uint8_t twoParamStore[2][2];
uint8_t switchStore[2];

bool readInputFromMidiDevice();
bool readInputFromMidiHost();
bool readInputFromMidiSerial();

void setCmd(uint8_t inputCmd);
void setCmdSwitch(uint8_t inputCmd1, uint8_t inputCmd2, uint8_t switchIndex);
void setCmdToggle(uint8_t inputCmd, uint8_t offset, uint8_t switchIndex);
void setCmdToggle(uint8_t inputCmd, uint8_t offset, uint8_t switchIndex);
void setCmdStep(uint8_t inputCmd, uint8_t param, uint8_t offset);
void setCmdParam(uint8_t inputCmd, uint8_t param);
void setCmdTwoParams(uint8_t inputCmd, uint8_t param, uint8_t position, uint8_t storeIndex);
void setPrefix(uint8_t cmdNum);
void setThisPrefix(char prefix[4]);
void removeTrailingUnderscore();

void createMap(){
  for (uint8_t i = 0; i < 128; i++)
  {
    notes[i] = 255;
    cc[i] = 255;
  }

  notes[60] = AVE55::WIPE_SQUARE_CORNER_UL;
  notes[61] = AVE55::WIPE_SQUARE_CORNER_DL;
  notes[62] = AVE55::WIPE_SQUARE_CORNER_DR;
  notes[63] = AVE55::WIPE_SQUARE_CORNER_UR;

  // else if(midiParam1 == 83){setCmdSwitch(AVE55::A_BUS_SOURCE_1, AVE55::A_BUS_BACK_COLOR, 0);}
  // else if(midiParam1 == 84){setCmdToggle(AVE55::WIPE_SQUARE_CORNER_UL, 8, 1);}

// if (midiParam1 == 60){setCmd(AVE55::WIPE_SQUARE_CORNER_UL);}
// else if (midiParam1 == 61){setCmd(AVE55::WIPE_SQUARE_CORNER_DL);}
// else if (midiParam1 == 62){setCmd(AVE55::WIPE_SQUARE_CORNER_DR);}
// else if (midiParam1 == 63){setCmd(AVE55::WIPE_SQUARE_CORNER_UR);}

  cc[0] = AVE55::A_B_MIX_LEVEL;
  // cc[0] = AVE55::A_B_MIX_LEVEL;

  // if(midiParam1 == 0){setCmdParam(AVE55::A_B_MIX_LEVEL, midiParam2);}
  // else if(midiParam1 == 1){setCmdTwoParams(AVE55::CENTER_WIPE, midiParam2, 0, 0);}
  // else if(midiParam1 == 2){setCmdTwoParams(AVE55::CENTER_WIPE, midiParam2, 1, 0);}
  // else if(midiParam1 == 3){setCmdStep(AVE55::WIPE_SQUARE_CORNER_UL, midiParam2, 8);}
  // else if(midiParam1 == 71){setCmdToggle(AVE55::WIPE_SQUARE_CORNER_UL, 8, 1);}


}

void setup()
{
  Serial1.begin(31250);
  Serial.begin(9600);
  altSerial.begin(9600);


  createMap();
  hasUsbDevice = false;
  vid = pid = 0;
  twoParamStore[2][2] = {};
  switchStore[2] = {};

  if (Usb.Init() == 0){ // means it is successful
    hasUsbDevice = true;
    delay( 200 );
    }


}

void loop()
{
  midiCommand = midiChannel =midiParam1 = midiParam2 = 0;
  cmdNum = 255;
  memset(&cmd[0], 0, sizeof(cmd));
  bool hasMessage = false;

  if(hasUsbDevice){hasMessage = readInputFromMidiDevice();} // check from the usbhost-sheild first if connected
  if(!hasMessage){hasMessage = readInputFromMidiHost();} // if nothing check the usb on the arduino
  if(!hasMessage){hasMessage = readInputFromMidiSerial();} // if still nothing check the serial port  
  if(!hasMessage){return;}


  if(midiCommand == 0){return;}
  if(midiChannel != 0){return;}

  Serial.print(midiParam1);
  Serial.print("<-note\n");
  Serial.print(midiChannel);
  Serial.print("<-channel\n");
  Serial.print(midiCommand);
  Serial.print("<-command\n"); 
  // midiParam2 = midiParam2 - 64; // weird off by 64 bug ??
  Serial.print(midiParam2);
  Serial.print("<-value\n\n");

  if(midiCommand == MIDICOMMAND::NOTEON && notes[midiParam1] != 255){
    cmdNum = notes[midiParam1];
    setPrefix(cmdNum);
    setCmd(cmdNum);
  }
  if(midiCommand == MIDICOMMAND::CC && cc[midiParam1] != 255){
    cmdNum = cc[midiParam1];
    Serial.print(cmdNum);
    Serial.print("<-cmdNum\n"); 
    setPrefix(cmdNum);
    setCmdParam(cmdNum, midiParam2);
  }
  
  removeTrailingUnderscore();

  Serial.print(cmd);
  Serial.print("<-cmd\n");
  if(cmd[0] == 0){return;}

  altSerial.write(2);
  altSerial.write(cmd);
  altSerial.write(3);
}

bool readInputFromMidiDevice(){
    Usb.Task();
    char buf[20];
    uint8_t bufMidi[3];
    uint16_t  rcvd;

  if (Midi.RecvData( &rcvd,  bufMidi) == 0 ) {
    uint8_t first =  bufMidi[1];
    midiCommand = first & 0xF0;
    midiChannel = first & 0xF;
    midiParam1 = bufMidi[2];
    midiParam2 = bufMidi[3];
    return true;
    }
  return false;
}

bool readInputFromMidiHost(){

  USBMIDI.poll();
  if(USBMIDI.available()){
    //Skip to beginning of next message (silently dropping stray data bytes)
    while(!(USBMIDI.peek() & 0x80)) USBMIDI.read();

    uint8_t first = USBMIDI.read();

    midiCommand = first & 0xF0; // command
    midiChannel = first & 0xF; // channel
    midiParam1 = USBMIDI.read(); // param 1 (note)
    midiParam2 = USBMIDI.read(); // param 2 (value)

    USBMIDI.flush();
    return true;
  }
  return false;
}

bool readInputFromMidiSerial(){

  if(Serial1.available() < 3){ return false;}
  //Skip to beginning of next message (silently dropping stray data bytes)
  while(!(Serial1.peek() & 0x80)){ Serial1.read(); }
  if(Serial1.available() < 3){ return false;}
  uint8_t first = Serial1.read();

  midiCommand = first & 0xF0; // command
  midiChannel = first & 0xF; // channel
  midiParam1 = Serial1.read(); // param 1
  midiParam2 = Serial1.read(); // param 2

  // Serial1.flush();
  while(Serial1.available()){Serial1.read();}
  return true;
}

void setThisPrefix(char prefix[4]){
  for (uint8_t i = 0; i < 3; i++)
  {
    cmd[i] = prefix[i];
  }
}
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

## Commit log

2020-01-05 link to power cap
2020-01-10 support midi host and device
2020-01-13 restructured project files
    [transcribe_circuit.kicad_pcb, transcribe_circuit.sch]
2020-01-14 works with and without usb-device connected now
    [transcribe_circuit.sch]
2020-01-17 update footprints, schematic and started pcb
    [transcribe_circuit.kicad_pcb, transcribe_circuit.sch]
2020-01-17 chipping away at pcb layout
    [transcribe_circuit.kicad_pcb, transcribe_circuit.sch]
2020-03-29 small pcb fixes
    [transcribe_circuit-B_Cu.gbl, transcribe_circuit-B_Mask.gbs, transcribe_circuit-B_Paste.gbp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]
2020-06-13 update circuit to v0.2
    [transcribe_circuit-B_Cu.gbl, transcribe_circuit-B_Cu.gbr, transcribe_circuit-B_Mask.gbr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]
2020-09-21 refactored the code and updated circuit
    [transcribe_circuit-B_Cu.gbl, transcribe_circuit-B_Cu.gbr, transcribe_circuit-B_Mask.gbr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]
2020-09-23 update circuit to 0.3 and add note to build guide for <=0.2
    [transcribe_circuit.kicad_pcb, transcribe_circuit.sch]
2020-10-26 Update README.md
    Changed the amounts of audio jacks and 1N4148. Corrected the links and article numbers to smaller 10kohm and 200 ohm resistors.
2021-07-14 revised circuit v0.4
    [full_bom.csv, mouser_bom.csv, tayda_bom.csv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]
2021-10-17 update a little
    [tayda_bom_10x.csv, transcribe_circuit.sch]
2022-01-11 folder refactor
    [full_bom.csv, mouser_bom.csv, tayda_bom.csv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]
2022-01-11 update to version 0.5
    [transcribe_circuit.kicad_pcb, transcribe_circuit.sch]
2022-02-22 update code and circuit revision
    [transcribe_circuit-B_Cu.gbl, transcribe_circuit-B_Mask.gbs, transcribe_circuit-B_Paste.gbp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]
2022-02-22 renamed kicad files
    [_transcribe_.kicad_pcb, _transcribe_.sch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]
2022-02-28 update bom
    [_transcribe_.csv, _transcribe_.kicad_pcb, _transcribe_.sch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]
2022-04-27 add booklet
    [_transcribe_.csv, _transcribe_.kicad_pcb, full_bom.csv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]
2022-11-27 uncomment the code
    [_transcribe_.kicad_pcb]
2023-02-08 add better logging for usb device
